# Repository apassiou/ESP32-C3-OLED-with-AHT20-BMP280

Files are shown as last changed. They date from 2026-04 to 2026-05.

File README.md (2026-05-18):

# ESP32-C3-OLED with AHT20+BMP280 - Weather Monitor
ESP32 C3 OLED with AHT20+BMP280 to read and output current temperature, humidity and barrometric pressure.

### Overview

This project will create a tiny box with  temperature,  humidity and atmospheric pressure readings. Atmospheric pressure trends over the course of the past hour are analyzed to determine (and display) if weather is getting worse or better (or is stable). Readings are made every 4 seconds. Temperature is displayed at all times and humidy and pressure readings swap every time there is a reading (every 4 seconds). This is due to the size of the screen, fitting 3 lines is possible but is far less readable from any distance.

The power draw on this setup is so insignificant that the USB power testers that I have are not be able to pick it up (ESP32 sleeps between readings). This means this device can be powered on from a portable battery pack 24/7 for months. Perfect for camping.

Chinese AliExpress ESP32-C3 OLED has non standard pinout. SDA/SCL are on pins 5/6 instead of 8/9
These same pins are used by the 0.43 inch OLED display
<div align="center">

</div>

### Wiring

Use 30AWG flexible wire, length ~1 inch. Solder the 4 pins from ATH20+BMP280 as follows.

| AHT20+BMP280 Pin | ESP32 Pin |
|---|---|
| VCC | 3.3V |
| GND | GND |
| SDA | GPIO 5 |
| SCL | GPIO 6 |

### Case

STL files provided:

* **Main Case** - Bottom cavity is for the AHT20+BMP280 board. Print with tree supports.
* **Divider** - Is inserted into the side channel in order to separate ESP32 from the AHT20+BMP280 board eliminate any heat from ESP32 reaching the sensors.
* **Lid** - Top lid (snaps into  place).

### Assembly and the Final Product

During assembly utilize the corner channels to feed the wires through (2 on each side). I found it easier by using a tool to push the wires to the side. You want flexible, thin (30awg) and short (sub 1 inch) wires for this.
<div align="center">


<br><br>

<br><br>

<br><br>

<br><br>


</div>

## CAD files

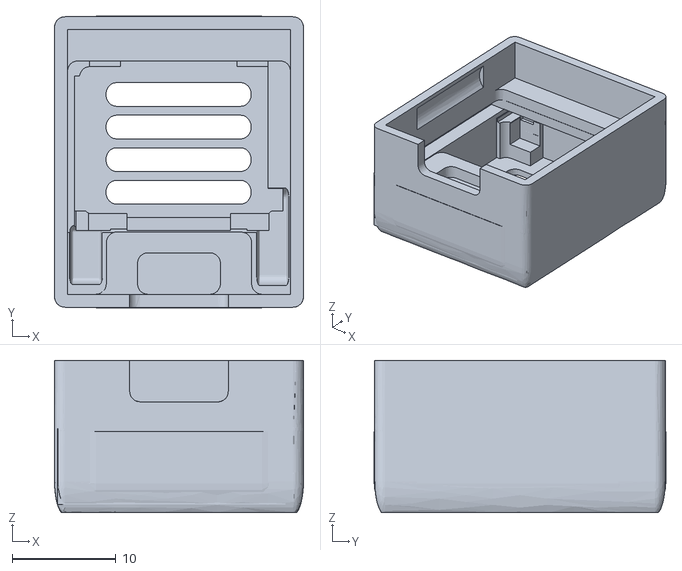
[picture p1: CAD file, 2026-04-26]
STL/Main Case.stl
24.0 x 28.1 x 14.7

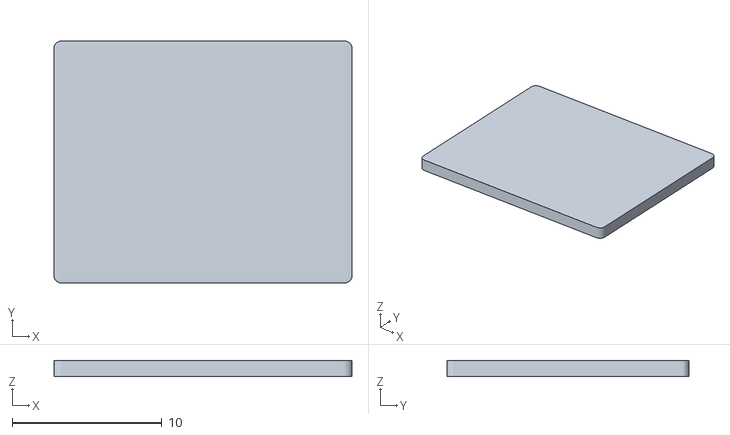
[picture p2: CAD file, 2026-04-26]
STL/Divider.stl
19.9 x 16.2 x 1.10

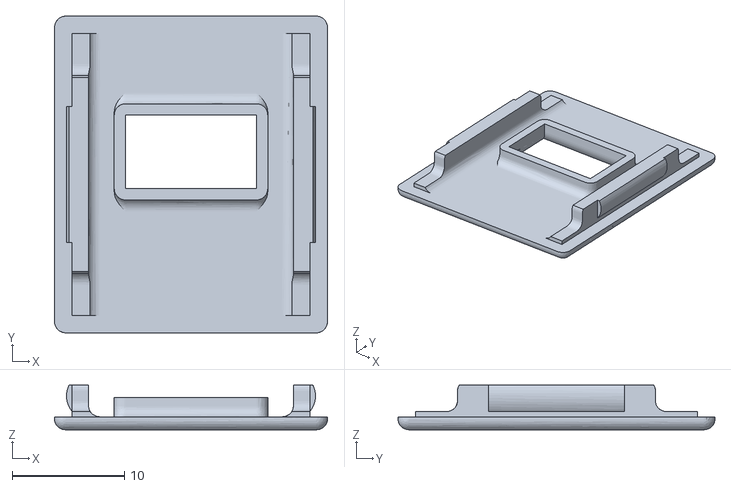
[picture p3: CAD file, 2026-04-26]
STL/Lid.stl
24.3 x 28.2 x 3.97

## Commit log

2026-04-26 Create esp32_c3_oled_code
    Initial commit
2026-04-26 Create ESP32-C3 OLED Code.c
    Initial Commit
2026-04-26 Update ESP32-C3 OLED Code.c
2026-04-26 STL files
    Case files
    [Divider.stl, Lid.stl, Main Case.stl]
2026-04-26 Rename Main Case.stl to STL/Main Case.stl
    [Main Case.stl]
2026-04-27 Update ESP32-C3 OLED Code.c
    Increased buffer for storing pressure to 2 hours (from 1 hour).
    Applied smoothing to pressure readings to eliminate spikes/jitter.
    Increased the weather patterns window to 1 hour (from 5 min).
    Added short term (15min) detection for sudden pressure drops/weather detection.
2026-05-18 Update ESP32-C3 OLED Code.c
    Set correct sun icon index (69)
